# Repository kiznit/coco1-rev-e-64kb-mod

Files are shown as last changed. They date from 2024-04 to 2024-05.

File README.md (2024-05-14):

# coco1-rev-e-64kb-mod
This project contains two breakout boards to upgrade a CoCo 1 Rev E from 32KB to 64KB without having to solder directly to U11 and U29.

- The first adapter for U29 (74LS02) has two PIN headers: one needs to be connected to **TP1** next to the CPU and the other to **U29** on U11's adapter.
- The second adapter for U11 (73LS138) has one PIN header that needs to be connected to **U11** on U29's adapter.

The **bin** folder contains zip files that can be uploaded directly to JLBPCB for production.

Update 2024/05/13:
I have assembled and tested the PCBs in my Rev E CoCo 1 and they work! I can now run 64 KB games like Sailor Man.

CoCo 1 Rev E with PCB boards - no wires
CoCo 1 Rev E with PCB boards - with wires
CoCo 1 Rev E with PCB boards - overview

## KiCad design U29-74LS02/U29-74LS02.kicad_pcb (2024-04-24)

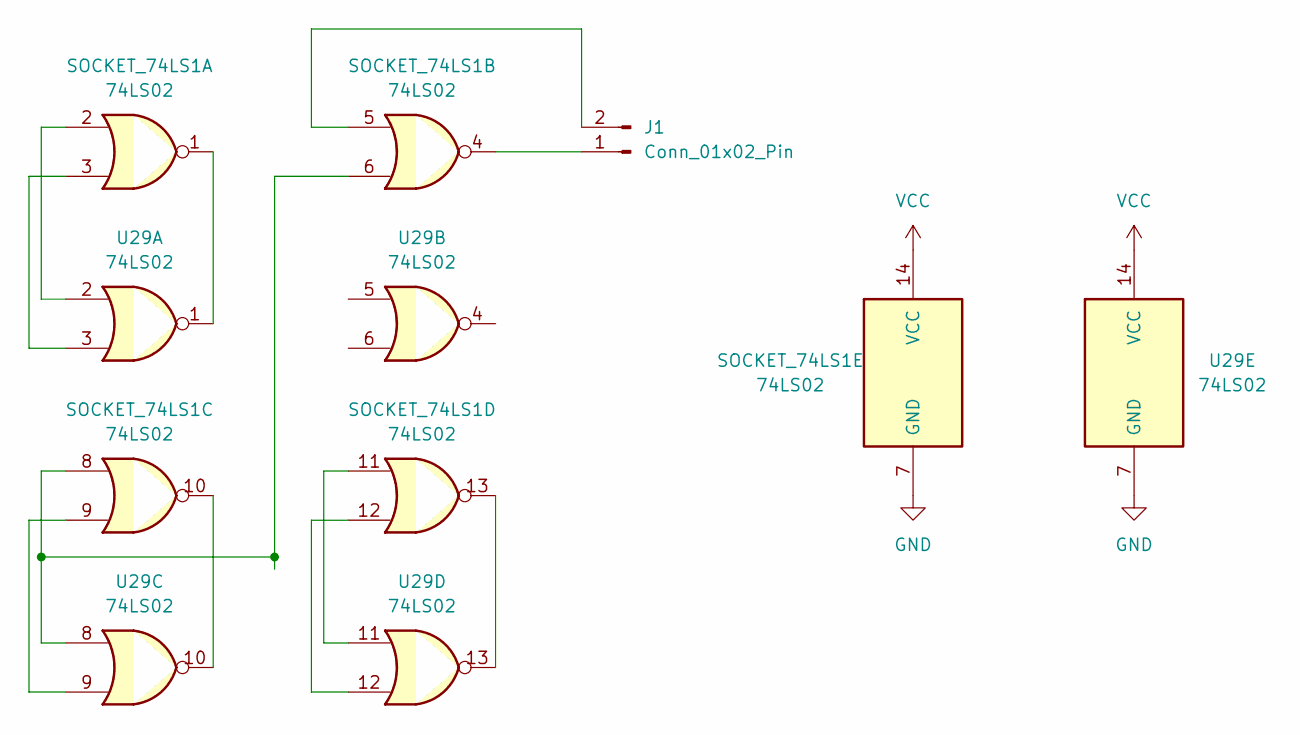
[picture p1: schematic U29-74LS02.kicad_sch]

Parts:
J1: Conn_01x02_Pin; PinHeader_1x02_P2.54mm_Vertical
SOCKET_74LS1: 74LS02; DIP-14_W7.62mm_Socket
U29: 74LS02; DIP-14_W7.62mm

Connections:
GND: SOCKET_74LS1.7 (GND), U29.7 (GND)
unnamed: J1.1, SOCKET_74LS1.4
unnamed: J1.2, SOCKET_74LS1.5
unnamed: SOCKET_74LS1.1, U29.1
unnamed: SOCKET_74LS1.2, U29.2
unnamed: SOCKET_74LS1.3, U29.3
unnamed: SOCKET_74LS1.6, SOCKET_74LS1.8, U29.8
unnamed: SOCKET_74LS1.9, U29.9
unnamed: SOCKET_74LS1.10, U29.10
unnamed: SOCKET_74LS1.11, U29.11
unnamed: SOCKET_74LS1.12, U29.12
unnamed: SOCKET_74LS1.13, U29.13
VCC: SOCKET_74LS1.14 (VCC), U29.14 (VCC)

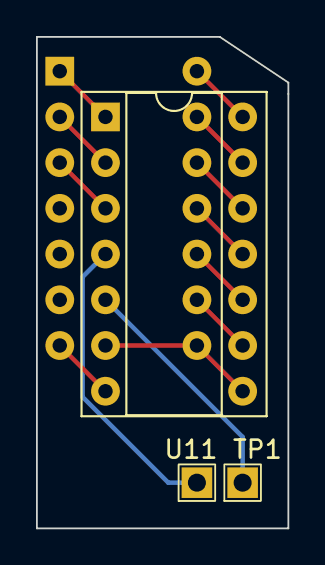
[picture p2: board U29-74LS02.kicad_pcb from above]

Board: 2 copper layers, 14.0 x 27.3 mm, 3 parts (0 on the bottom side), 13 nets.

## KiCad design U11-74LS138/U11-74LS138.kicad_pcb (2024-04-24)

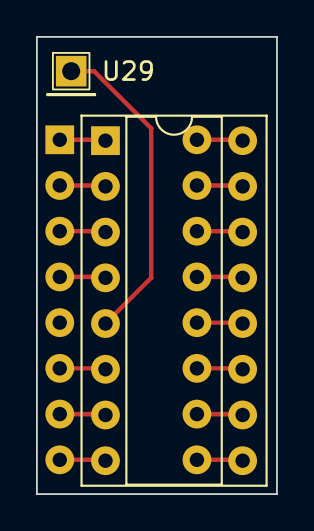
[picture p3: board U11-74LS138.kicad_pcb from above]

Board: 2 copper layers, 13.3 x 25.4 mm, 3 parts (0 on the bottom side), 16 nets.

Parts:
SOCKET_74LS1: 74LS138; DIP-16_W7.62mm_Socket
U29: Conn_01x01_Pin; PinHeader_1x01_P2.54mm_Vertical
Ue: 74LS138; DIP-16_W7.62mm

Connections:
GND: SOCKET_74LS1.8 (GND), Ue.8 (GND)
unnamed: SOCKET_74LS1.5 (E2), U29.1
unnamed: SOCKET_74LS1.1 (A0), Ue.1 (A0)
unnamed: SOCKET_74LS1.2 (A1), Ue.2 (A1)
unnamed: SOCKET_74LS1.3 (A2), Ue.3 (A2)
unnamed: SOCKET_74LS1.4 (E1), Ue.4 (E1)
unnamed: SOCKET_74LS1.6 (E3), Ue.6 (E3)
unnamed: SOCKET_74LS1.15 (O0), Ue.15 (O0)
unnamed: SOCKET_74LS1.14 (O1), Ue.14 (O1)
unnamed: SOCKET_74LS1.13 (O2), Ue.13 (O2)
unnamed: SOCKET_74LS1.12 (O3), Ue.12 (O3)
unnamed: SOCKET_74LS1.11 (O4), Ue.11 (O4)
unnamed: SOCKET_74LS1.10 (O5), Ue.10 (O5)
unnamed: SOCKET_74LS1.9 (O6), Ue.9 (O6)
unnamed: SOCKET_74LS1.7 (O7), Ue.7 (O7)
VCC: SOCKET_74LS1.16 (VCC), Ue.16 (VCC)
